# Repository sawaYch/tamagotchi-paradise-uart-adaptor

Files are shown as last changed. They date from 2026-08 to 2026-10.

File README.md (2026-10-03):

# Tamagotchi Paradise UART Adaptor



<figure>
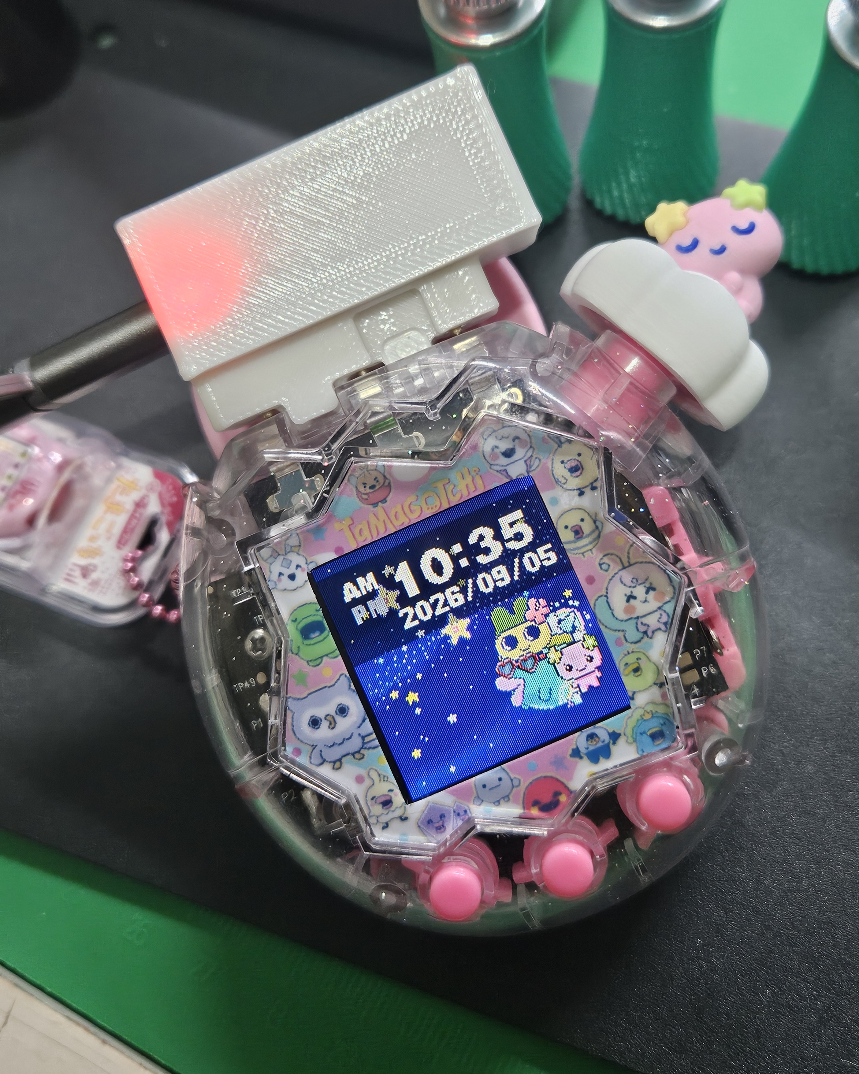
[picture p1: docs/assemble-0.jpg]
assemble-0

<figcaption>My adaptor plug to a Tamagotchi Paradise device 💗💖</figcaption>
</figure>

## Introduction

This is a UART adaptor for connecting your personal computer to Tamagotchi Paradise via `USB Type-C` cable.

## Install OpenSCAD

This project use OpenSCAD script to model the adaptor

```bash
# Windows
winget install -e --id OpenSCAD.OpenSCAD

# MacOS
brew install --cask openscad@snapshot
```

## Install just

```bash
# Windows
winget install -e --id Casey.Just

# MacOS
brew install just
```

## Generate .stl for 3D printing

Generate the printable wired adapter and lid:

```bash
just wire
```

Generate the printable wireless adapter and lid:

```bash
just wireless
```

Generate both with `just all`.

## Models

[Wired adapter](./models/wire/wire-adaptor.stl) · [Wired lid](./models/wire/wire-lid.stl) · [Wireless adapter](./models/wireless/wireless-adaptor.stl) · [Wireless lid](./models/wireless/wireless-lid.stl) · [Wireless tray cover](./models/wireless/wireless-tray-cover.stl)

## Components

### 1. FTL232RL USB to ttl module (USB Type-C)

<div style="display: flex; gap: 0px;">
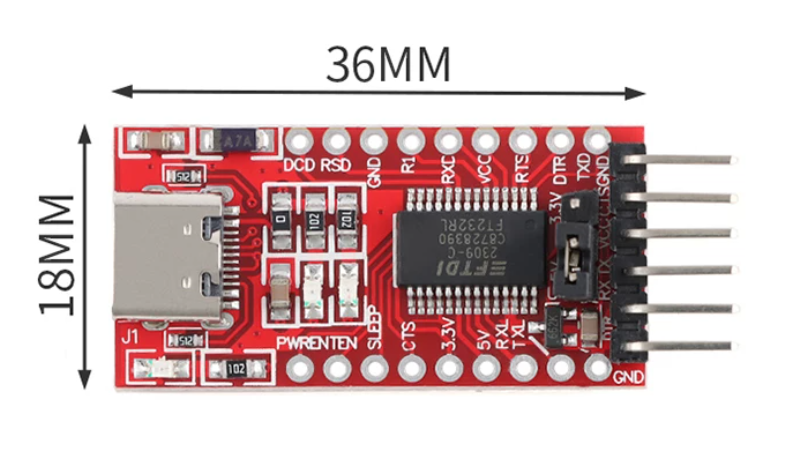
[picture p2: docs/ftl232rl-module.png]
ftl232rl-module
  
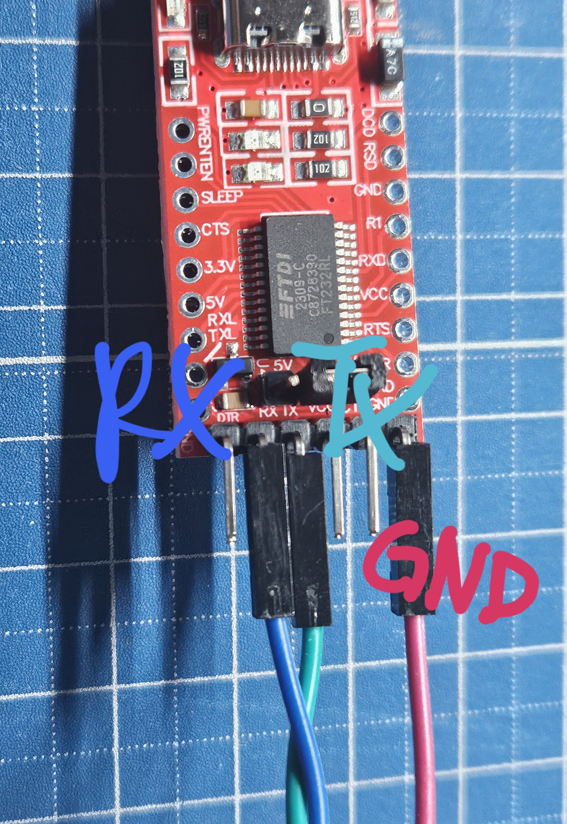
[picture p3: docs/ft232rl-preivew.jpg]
ftl232rl-preview
   
</div>

[Example Retail](https://item.taobao.com/item.htm?id=977654905255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)

🚨🚨🚨 **Tamagotchi Paradise only accept 3.3v for signal, please check your usb to ttl TX is output 3.3v otherwise it can damage your Tamagotchi Paradise device!!!** 🚨🚨🚨

Requirement:

- Tamagotchi Paradise require input signal with 3.3v, otherwise the command will failed / damage your tamagotchi device
- Baud rate need to support 460800

### 2. Pogo pins

It used for contact the top portion of the physical connector pins from Tamagotchi Paradise device. Notices that the size does matter.
Here I use A-SMT pin, (flat flange, no tail) with following spec:

```
Ø3 × 0.5 mm flange
Ø2 × 7.0 mm barrel
Ø1.5 × 2.5 mm plunger
10 mm overall.
```

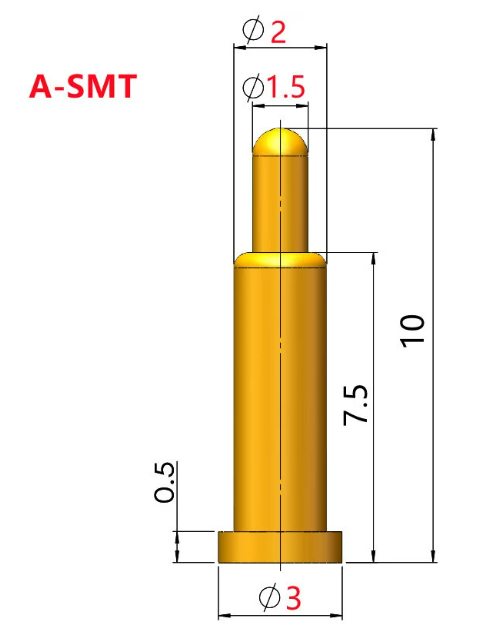
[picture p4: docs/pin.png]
pogopin
   
[Example Retail](https://item.taobao.com/item.htm?id=836549063705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)

### 3. Wire for soldering

Any wire (suggest to use 24 AWG) for soldering TX, RX, GND to the pogo pins.

## Connection Scheme

Soldering the pin reference to the following scheme, the left side of the adaptor plug your own USB type-c cable to your PC.

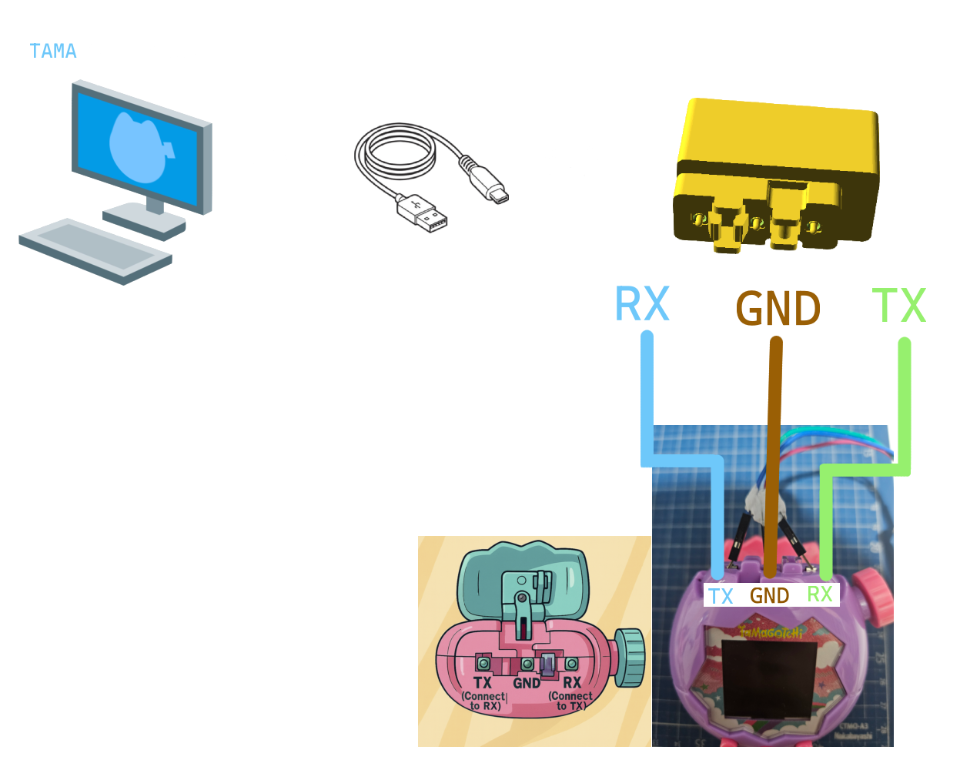
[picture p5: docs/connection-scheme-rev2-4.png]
connection-scheme
  

## Gallery
_Model 3D Print in FDM ABS_
<div style="display: flex; gap: 0px;">
asm-0  
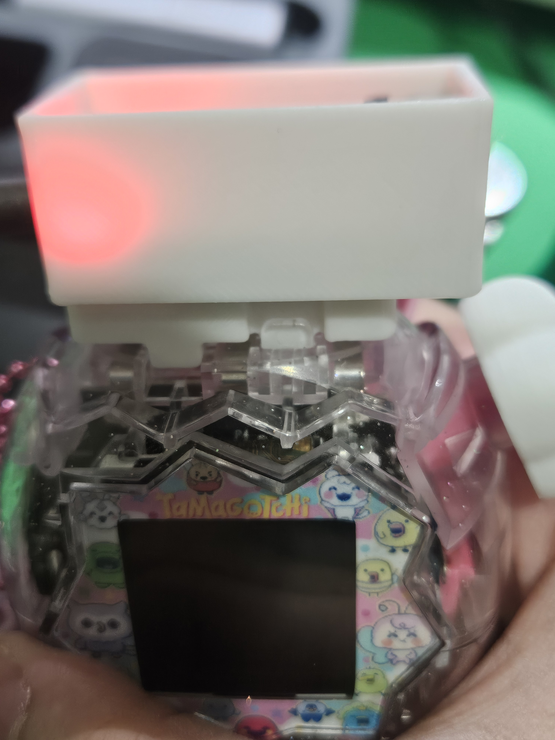
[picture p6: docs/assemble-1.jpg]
asm-1
  
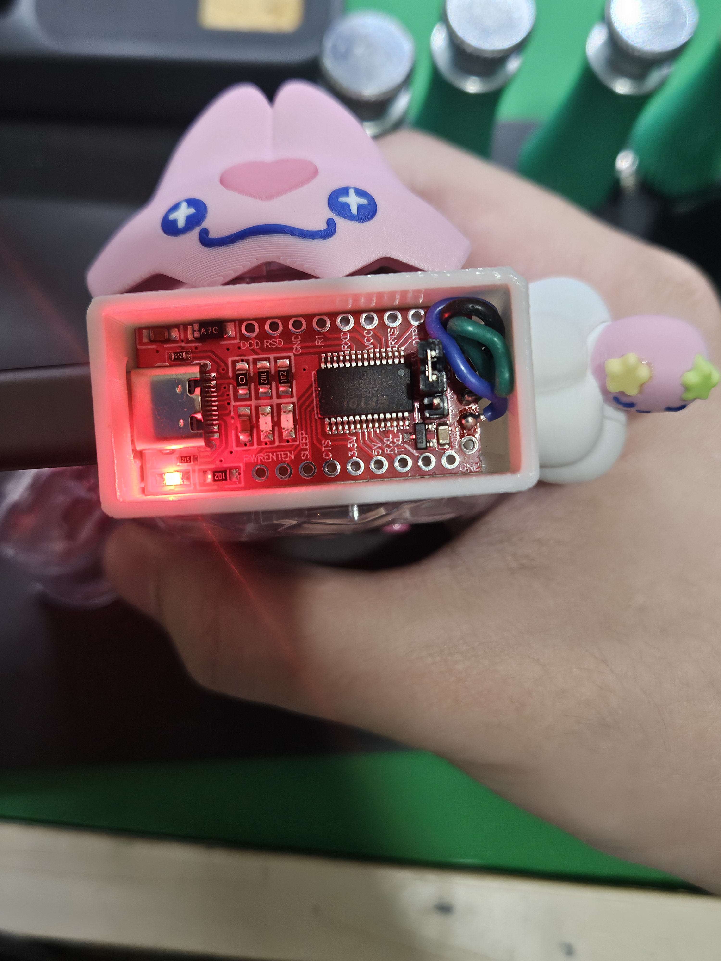
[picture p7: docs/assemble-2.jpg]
asm-2

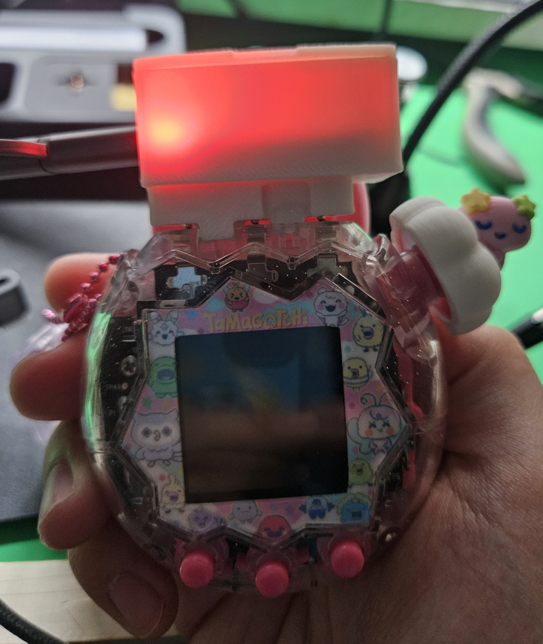
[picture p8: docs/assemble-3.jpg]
asm-3
     
</div>

## Special Thanks

This project reference and modified from hook model `./reference-stl/Basic_rev2.stl` [IgelFullmetal](https://www.thingiverse.com/thing:7310297) Creative Common License

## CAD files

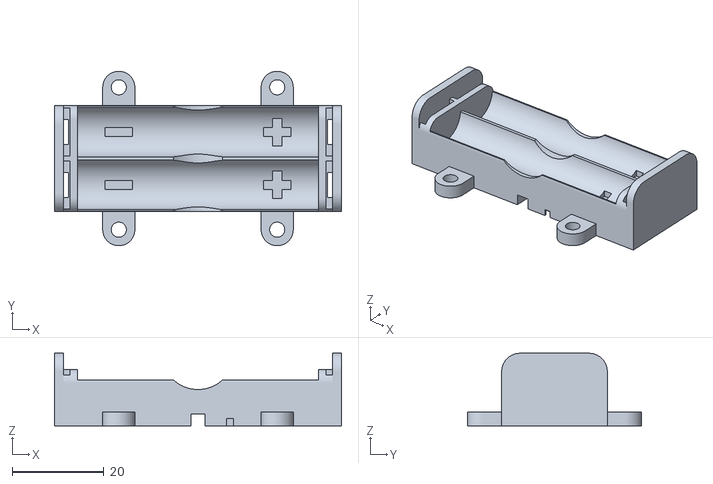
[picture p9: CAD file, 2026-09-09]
battery-box-aaa.stl
62.5 x 38.0 x 15.8

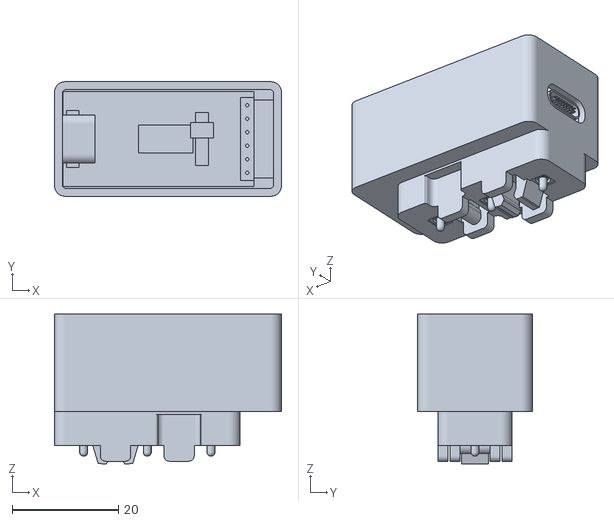
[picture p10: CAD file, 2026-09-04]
docs/preview-no-lid.stl
42.8 x 21.6 x 28.2

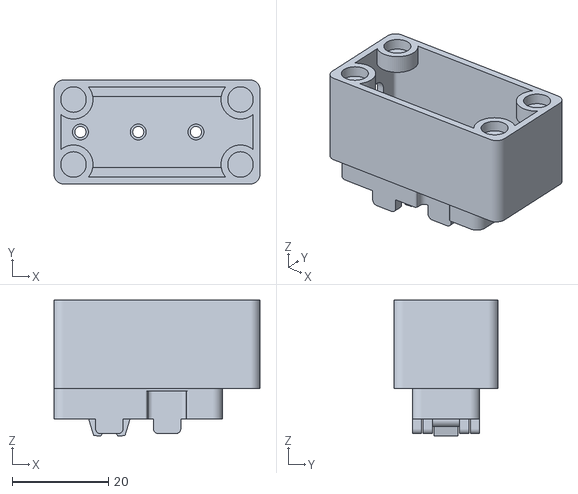
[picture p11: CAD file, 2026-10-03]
models/wire/wire-adaptor.stl
42.8 x 21.6 x 28.2

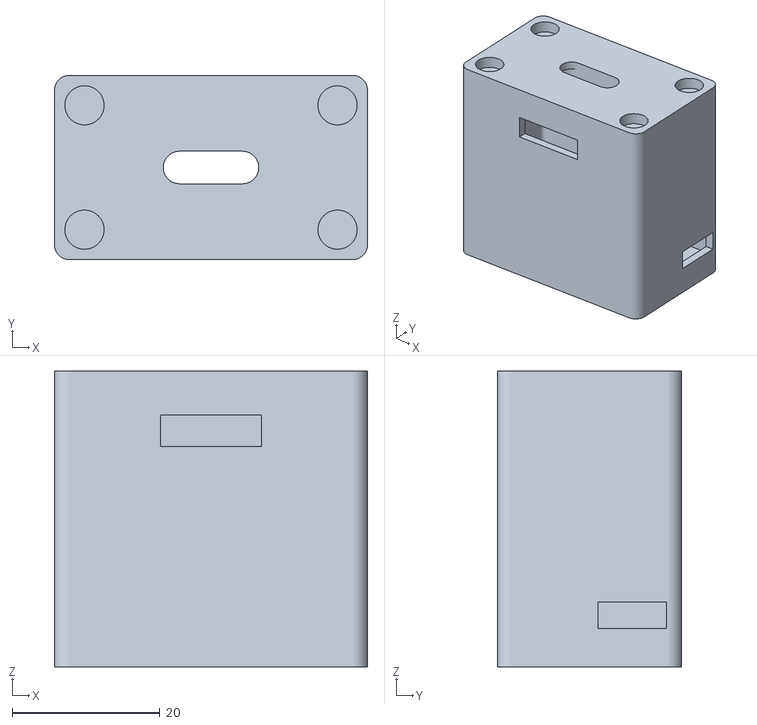
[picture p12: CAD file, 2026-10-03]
models/wireless/wireless-lid.stl
42.3 x 24.9 x 39.9

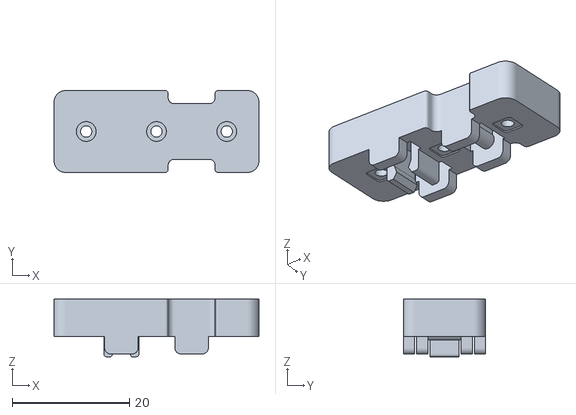
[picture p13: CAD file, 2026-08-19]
reference-stl/Basic_rev2.stl
35.0 x 14.0 x 9.85

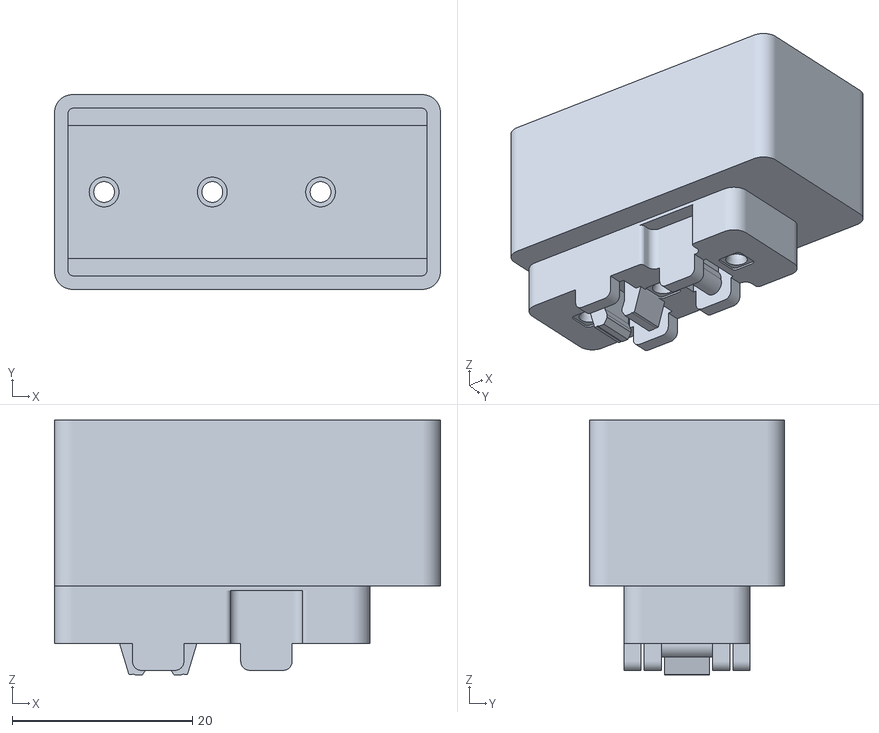
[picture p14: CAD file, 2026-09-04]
adapter.stl
42.8 x 21.6 x 28.2

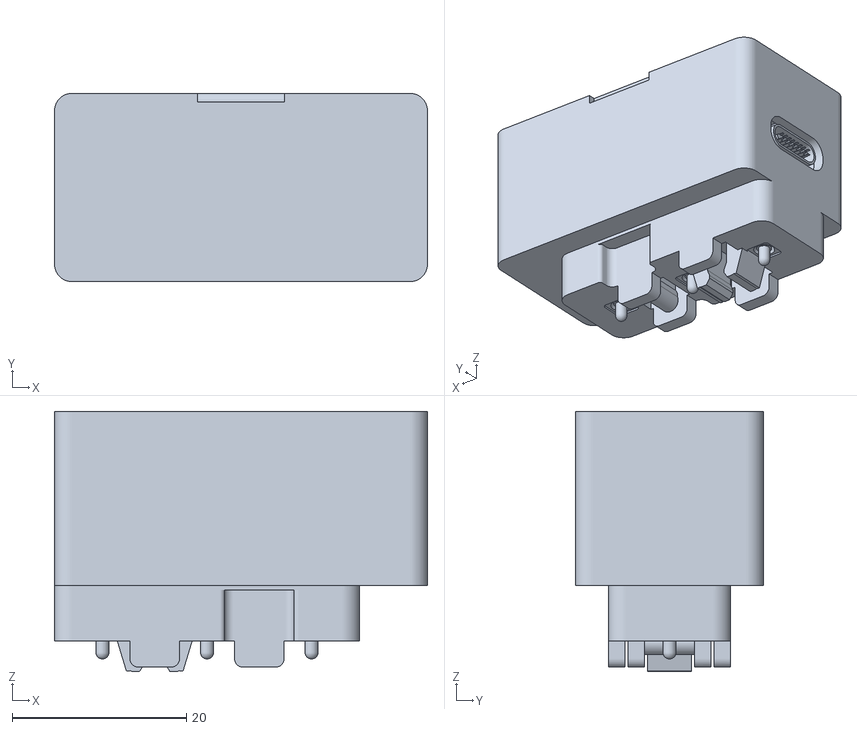
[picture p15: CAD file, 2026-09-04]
docs/preview-with-lid.stl
42.8 x 21.6 x 29.9

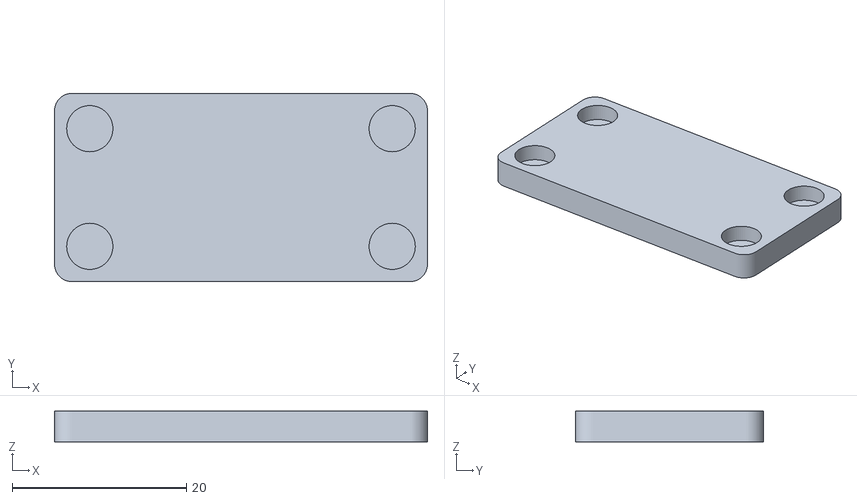
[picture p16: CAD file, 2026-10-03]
models/wire/wire-lid.stl
42.8 x 21.6 x 3.55

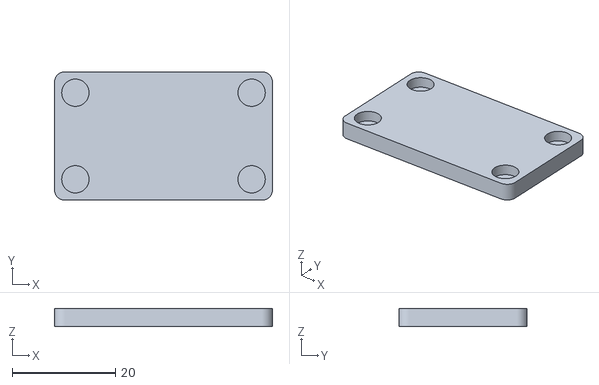
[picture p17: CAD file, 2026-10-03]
models/wireless/wireless-tray-cover.stl
42.3 x 24.9 x 3.55

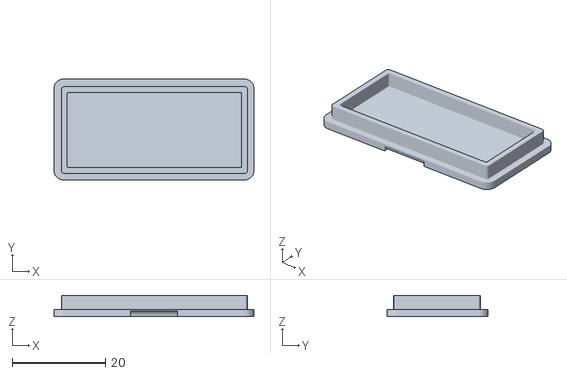
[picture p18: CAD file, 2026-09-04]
lid.stl
42.8 x 21.6 x 4.60

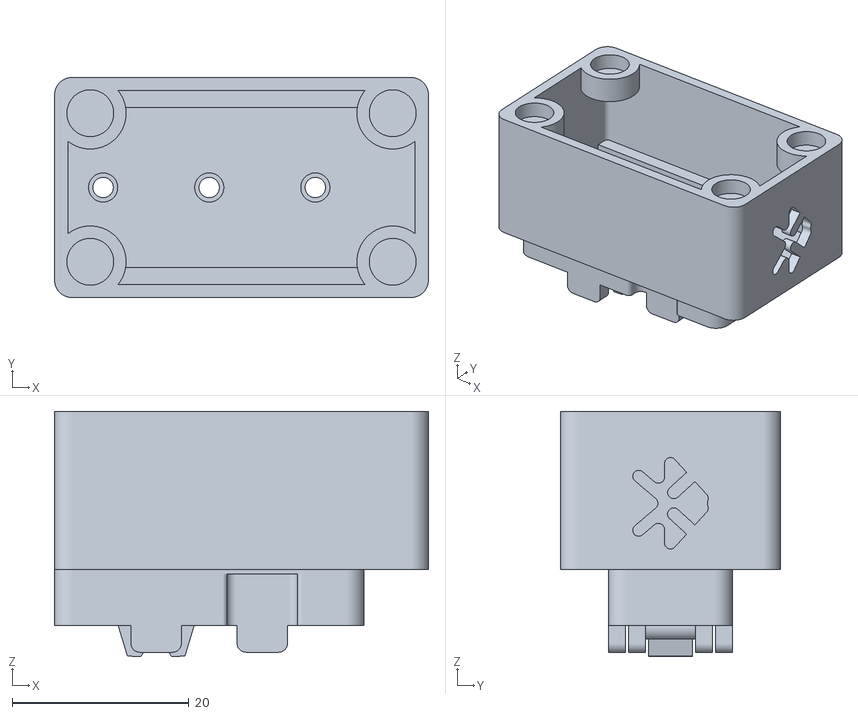
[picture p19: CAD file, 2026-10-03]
models/wireless/wireless-adaptor.stl
42.3 x 24.9 x 27.8

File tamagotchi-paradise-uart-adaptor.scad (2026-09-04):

// Tamagotchi Paradise UART adapter
// Hook (Basic_rev2.stl) + FT232RL pocket + internal friction-fit lid.

$fn = 64;
eps = 0.05;

tolerance = 0.2;
show_board_preview = true;
show_pin_preview = true;

// 0 = adapter, 1 = lid, 2 = assembled
// Use a number so `openscad -D part=0` works on Windows (no quoted strings).
part = 0;

// --- FT232RL USB-C module (36 x 18 mm) ---
pcb_l = 36.0;
pcb_w = 18.0;
pcb_thickness = 1.6;
jumper_h = 9.0;
pcb_h = pcb_thickness + jumper_h;
usb_w = 9.0;
usb_h = 3.2;
usb_overhang = 1.2;
usb_shell_l = 7.2;
usb_shell_w = 9.0;
usb_shell_h = 3.2;
header_overhang = 2.0;
pad_pitch_y = 2.54;
board_preview_angle = 0;
pcb_insert_x_offset = 0;
pcb_insert_y_offset = 0;

// --- Hook ---
stl_file = "reference-stl/Basic_rev2.stl";
hook_l = 35.0;
hook_w = 14.0;
hook_h = 6.35;
hook_r = 2.0;

// A-SMT pogo (pin.png), installed plunger-down, flange on pocket floor
pin_xs = [-12, 0, 12];
pin_flange_d = 3.0;
pin_flange_h = 0.5;
pin_barrel_d = 2.0;
pin_barrel_h = 7.0;
pin_tip_d = 1.5;
pin_tip_h = 2.5;
pin_hole_clear = 0.15;
pin_sleeve_od = 3.7;
pin_sleeve_z = 3.2;

// --- Pocket / lid ---
wall = 1.6;
wall_inner = wall - 0.1;
headroom = 0.6;
shell_extra = 2;

// Space under the PCB: solder fillet + 24 AWG + user-added isolator sheet
solder_h = 1.0;
wire_od = 1.4;
isolator_h = 1.0;
solder_well_h = solder_h + wire_od;
board_lift = solder_well_h + isolator_h;
ledge_w = 1.8;
ledge_h = 1.2;

usb_cut_tol = 0.6;
usb_cut_round_r = 2.5;

lid_t = 1.6;
lid_inner_clear = 0.03;
lid_inner_h = 3.0;
lid_inner_t = 1.2;
lid_snap_d = 0.5;
lid_snap_h = 1.6;
lid_snap_w = 14.0;
lid_snap_lift = 0.7;
lid_pry_w = 10.0;
lid_pry_d = 1.2;

// --- Hook reinforcement (imported Basic_rev2.stl) ---
prong_root_y = -2.5;
prong_root_w = 5.0;
prong_root_depth = 3.45;
prong_root_extra = 1.25;
prong_root_overlap = 0.25;

// Detent faces that clip the Tamagotchi's grab bar (measured from STL)
prong_grab_shave = 0.1;
prong_grab_face_l = -7.112;
prong_grab_face_r = -4.888;
prong_grab_z = -2.49;

grab_cyl_x = 6.0;
grab_cyl_z = -0.20;
grab_cyl_d = 2.64; // original = ~2.4mm
grab_cyl_len = 5.7;

// --- Derived ---
pcb_cav_l = pcb_l + 2 * tolerance + usb_overhang + header_overhang;
pcb_cav_w = pcb_w + 2 * tolerance;
pcb_cav_h = pcb_h + tolerance + headroom;
shell_h = wall + board_lift + pcb_cav_h + shell_extra;

usb_cut_w = usb_w + 2 * tolerance + 0.6;
usb_cut_h = usb_h + 2 * tolerance;

hook_x0 = -hook_l / 2;
hook_y0 = -hook_w / 2;
shell_x0 = hook_x0;
shell_l = pcb_cav_l + 2 * wall;
shell_x1 = shell_x0 + shell_l;
shell_y0 = -pcb_cav_w / 2 - wall;
shell_y1 = pcb_cav_w / 2 + wall;
shell_w = shell_y1 - shell_y0;
shell_ox = shell_x0 + pcb_insert_x_offset;
shell_oy = shell_y0 + pcb_insert_y_offset;

pin_barrel_hole = pin_barrel_d + 2 * pin_hole_clear;
pin_flange_hole = pin_flange_d + 2 * pin_hole_clear;
pin_floor_z = hook_h + wall;
pin_seat_z = pin_floor_z - pin_flange_h;
pcb_z = pin_floor_z + board_lift;
ledge_z = pin_floor_z + solder_well_h - ledge_h;

if (part == 1) {
    lid();
} else {
    adapter();
    if (part == 2)
        color([0.25, 0.55, 0.85, 0.72])
            lid();
}

module adapter() {
    union() {
        difference() {
            union() {
                hook();
                pcb_shell();
                pin_sleeves();
                prong_root_reinforcement();
                grab_cylinder();
            }
            pcb_cavity();
            usb_cutout();
            pin_through_holes();
            prong_grab_relief();
            //lid_inner_snap_recesses();
        }
        isolator_ledges();
    }
    if (show_board_preview)
        board_preview();
    if (show_pin_preview)
        pin_preview();
}

module hook() {
    import(stl_file, convexity = 16);
}

module pcb_shell() {
    translate([shell_ox, shell_oy, hook_h])
        rounded_cube([shell_l, shell_w, shell_h], hook_r);

    translate([hook_x0, hook_y0, hook_h - 0.5])
        rounded_cube([hook_l, hook_w, 0.5 + eps], hook_r);
}

module pcb_cavity() {
    translate([shell_ox + wall_inner, shell_oy + wall_inner, hook_h + wall])
        rounded_cube([
            shell_l - 2 * wall_inner,
            shell_w - 2 * wall_inner,
            shell_h - wall + 1
        ], 0.6);
}

module usb_cutout() {
    cut_w = usb_cut_w + 2 * usb_cut_tol;
    cut_h = usb_cut_h + 2 * usb_cut_tol;
    depth = wall + 6;
    r = min(usb_cut_round_r, cut_w / 2 - 0.2, cut_h / 2 - 0.2);
    x0 = shell_ox - 0.2;
    y0 = shell_oy + (shell_w - cut_w) / 2;
    z0 = pcb_z + pcb_thickness + usb_h / 2;

    translate([x0, y0 + cut_w / 2, z0])
        rotate([0, 90, 0])
            linear_extrude(height = depth)
                offset(r = r)
                    square([cut_h - 2 * r, cut_w - 2 * r], center = true);
}

module pin_sleeves() {
    h = pin_floor_z - pin_sleeve_z + 0.2;
    for (x = pin_xs)
        translate([x, 0, pin_sleeve_z])
            cylinder(h = h, d = pin_sleeve_od);
}

module pin_through_holes() {
    for (x = pin_xs) {
        translate([x, 0, -1])
            cylinder(h = pin_floor_z + 2, d = pin_barrel_hole);
        translate([x, 0, pin_seat_z])
            cylinder(h = pin_flange_h + 1, d = pin_flange_hole);
        translate([x, 0, -0.2])
            cylinder(h = 1.2, d1 = pin_barrel_hole + 0.8, d2 = pin_barrel_hole);
    }
}

module pin_preview() {
    for (x = pin_xs)
        translate([x, 0, pin_seat_z])
            pogo_pin();
}

module pogo_pin() {
    color([0.90, 0.75, 0.20, 0.95]) {
        cylinder(h = pin_flange_h, d = pin_flange_d);
        translate([0, 0, -pin_barrel_h])
            cylinder(h = pin_barrel_h, d = pin_barrel_d);
        translate([0, 0, -pin_barrel_h - pin_tip_h + pin_tip_d / 2]) {
            cylinder(h = pin_tip_h - pin_tip_d / 2, d = pin_tip_d);
            sphere(d = pin_tip_d);
        }
    }
}

module board_preview() {
    board_x0 = hook_x0 + wall;
    board_y0 = -pcb_w / 2;
    ic_l = 10.3;
    ic_w = 5.3;
    ic_h = 1.65;
    jumper_x = board_x0 + 26.2;
    jumper_post_h = 2.5;
    header_x = board_x0 + pcb_l - 2.5;
    header_body_w = 6 * pad_pitch_y + 0.5;

    translate([pcb_insert_x_offset, pcb_insert_y_offset, pcb_z])
        rotate([0, 0, board_preview_angle])
            union() {
                color([0.78, 0.12, 0.14, 0.82])
                    translate([board_x0, board_y0, 0])
                        cube([pcb_l, pcb_w, pcb_thickness]);

                translate([board_x0 - usb_overhang, 0, pcb_thickness])
                    usb_c_receptacle();

                color([0.10, 0.10, 0.10, 0.96])
                    translate([
                        board_x0 + 14.2,
                        -ic_w / 2,
                        pcb_thickness
                    ])
                        cube([ic_l, ic_w, ic_h]);

                color([0.12, 0.12, 0.12, 0.96])
                    translate([
                        jumper_x - 1.25,
                        -pad_pitch_y * 1.5 - 1.2,
                        pcb_thickness
                    ])
                        cube([2.5, pad_pitch_y * 3 + 2.4, jumper_post_h]);

                color([0.08, 0.08, 0.08, 0.96])
                    translate([jumper_x - 2.2, 0.2, pcb_thickness + jumper_post_h])
                        cube([4.4, pad_pitch_y + 0.4, jumper_h - jumper_post_h]);

                color([0.12, 0.12, 0.12, 0.96])
                    translate([
                        header_x,
                        -header_body_w / 2,
                        pcb_thickness
                    ])
                        cube([2.5, header_body_w, 2.5]);

                for (p = [1 : 6]) {
                    py = (3.5 - p) * pad_pitch_y;
                    pin_col =
                        p == 2 ? [0.35, 0.72, 0.95, 0.95] :
                        p == 3 ? [0.25, 0.85, 0.40, 0.95] :
                        p == 6 ? [0.55, 0.32, 0.16, 0.95] :
                                 [0.82, 0.68, 0.18, 0.92];

                    translate([header_x + 1.25, py, pcb_thickness + 2.5])
                        color(pin_col)
                            cylinder(h = 4.2, d = 0.64);
                }
            }
}

module usb_c_receptacle() {
    w = usb_shell_w;
    h = usb_shell_h;
    l = usb_shell_l;
    metal_t = 0.32;
    cavity_l = 5.5;
    inner_w = w - 2 * metal_t;
    inner_h = h - 2 * metal_t;
    tongue_w = 6.55;
    tongue_h = 0.72;
    tongue_l = 4.3;
    tab_l = 2.4;
    tab_w = 0.85;
    tab_h = 0.28;

    color([0.76, 0.78, 0.81, 0.96])
        difference() {
            usb_c_capsule(l, w, h);
            translate([-eps, 0, metal_t])
                usb_c_capsule(cavity_l + eps, inner_w, inner_h);
        }

    color([0.10, 0.10, 0.11, 0.96]) {
        translate([cavity_l - 0.35, 0, metal_t + 0.08])
            usb_c_capsule(l - cavity_l + 0.35, inner_w - 0.2, inner_h - 0.16);
        translate([0.28, 0, (h - tongue_h) / 2])
            usb_c_capsule(tongue_l, tongue_w, tongue_h);
    }
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

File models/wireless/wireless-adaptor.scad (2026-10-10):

// Tamagotchi Paradise wireless UART adapter
// Hook (Basic_rev2.stl) + JDY-23 BLE pocket + magnetic power tray + cover.

$fn = 64;
eps = 0.05;

tolerance = 0.2;
show_board_preview = false;
show_pin_preview = false;
show_magnet_preview = false;

// 0 = adapter, 1 = power tray, 2 = assembled, 3 = tray cover
// Use a number so `openscad -D part=0` works on Windows (no quoted strings).
part = 2;

// --- JDY-23 BLE 5.0 module with base plate (32.7 x 18.3 mm) ---
pcb_l = 32.7;
pcb_w = 18.3;
pcb_thickness = 1.6;
// SMT module stack on the carrier (~19.6 x 14.94 x 1.8) plus pin header clearance
module_l = 19.6;
module_w = 14.94;
module_h = 1.8;
header_h = 8.5;
pcb_h = pcb_thickness + header_h;
pad_pitch_y = 2.54;
board_preview_angle = 0;
pcb_insert_x_offset = 0;
pcb_insert_y_offset = 0;

// --- Hook ---
stl_file = "../../reference-stl/Basic_rev2.stl";
hook_l = 35.0;
hook_w = 14.0;
hook_h = 6.35;
hook_r = 2.0;

// A-SMT pogo (pin.png), installed plunger-down, flange on pocket floor
pin_xs = [-12, 0, 12];
pin_flange_d = 3.0;
pin_flange_h = 0.5;
pin_barrel_d = 2.0;
pin_barrel_h = 7.0;
pin_tip_d = 1.5;
pin_tip_h = 2.5;
pin_hole_clear = 0.15;
pin_sleeve_od = 3.7;
pin_sleeve_z = 3.2;

// --- Pocket / lid ---
wall = 1.6;
wall_inner = wall - 0.1;
// JLC3DP: walls > 1.2 mm, and nothing thinner than 0.8 mm.
min_wall = 1.4;
headroom = 0.6;
shell_extra = 2;

// Extra pocket around the JDY-23 pin header for soldering TX/RX/GND/VCC wires
pin_solder_clear = 6.0; // along X, ahead of the header (toward pogo pins)
side_wire_clear = 1.5; // each Y side beyond fit tolerance

// Bluetooth-symbol windows on both end walls
ble_symbol_h = 9.0;
ble_symbol_stroke = 1.35;

// Space under the PCB: solder fillet + 24 AWG + user-added isolator sheet
solder_h = 1.0;
wire_od = 1.4;
isolator_h = 1.0;
solder_well_h = solder_h + wire_od;
board_lift = solder_well_h + isolator_h;
ledge_w = 1.8;
ledge_h = min_wall;

// 5 x 2 mm N52 discs, one pair at each corner. 2 mm is thick enough to
// hold this lid (~0.6 kg pull per magnet) without a deep pocket.
mag_d = 5.0;
mag_h = 2.0;
mag_fit = 0.3;
mag_pocket_d = mag_d + mag_fit;
mag_pocket_h = mag_h + 0.15;
mag_floor = min_wall;
mag_wall_skin = min_wall;
mag_inset = mag_pocket_d / 2 + mag_wall_skin;
mag_boss_d = mag_pocket_d + 2 * min_wall;
mag_boss_h = mag_pocket_h + mag_floor;

// Female pogo housing in tray floor (ears seat on a ledge, insert from the lid cavity)
fp_body_l = 12.5;
fp_ear_l = 14.5;
fp_w = 4.0;
fp_h = 4.0;
fp_ear_t = 1.0;
fp_fit = 0.2;

// --- Power tray components ---
// 102535 LiPo 1000 mAh
batt_l = 35.0;
batt_w = 25.0;
batt_t = 10.0;
// MiniUPS-3.3V
ups_l = 35.0;
ups_w = 21.0;
ups_t = 5.6;
// SS-12D10-G5 slide switch
sw_l = 12.7;
sw_w = 6.7;
sw_h = 11.3;
sw_body_h = 6.5;
sw_act_travel = 2.2;
sw_act_l = 11.5;
sw_act_h = 4.2;
// Vertical USB-C opening on the +X end wall (plug long axis along Z).
// Insets are from the outer case to the opening edges.
usbc_w = 3.6;
usbc_h = 9.5;
usbc_side_inset = 3.5;
usbc_top_inset = 16.0;
// Status-LED grille just above that opening
led_hole_d = 1.5;
led_hole_pitch = 2.5;
led_hole_cols = 5;
led_hole_rows = 3;
led_hole_gap = 1.6;

comp_fit = 0.4;
// Battery stands on its thin face so tray width can match the adapter:
// footprint 35(L)×10(T), height 25(W) — makes the lid taller.
batt_bay_l = batt_l + comp_fit;
batt_bay_w = batt_t + comp_fit;
batt_bay_h = batt_w + comp_fit;
ups_pl = ups_l + comp_fit;
ups_pw = ups_w + comp_fit;
ups_pt = ups_t + 0.2;
sw_pl = sw_l + 0.4;
sw_pw = sw_w + 0.3;

tray_roof = 0.8;
tray_floor = fp_h + tray_roof;
// Lip must clear corner magnet bosses above the MiniUPS
tray_lip = mag_boss_h + 0.4;
tray_gap_sw = 0.6;
tray_inner_l = max(batt_bay_l, ups_pl) + 1.0;
tray_cavity_h = batt_bay_h + ups_pt + tray_lip;
tray_h = tray_floor + tray_cavity_h;
cover_h = mag_pocket_h + mag_floor;
cover_pry_w = 10.0;
cover_pry_d = 1.2;
pogo_wire_slot_w = 2.2;
pogo_wire_slot_l = 6.0;

// Kuchipatchi outline on the plain long wall, opposite the slide switch.
kuchipatchi_margin_z = 2.6;
kuchipatchi_depth = 0.4;
// Height of kuchipatchi.svg as imported, in mm.
kuchipatchi_art_h = 34.75;

// Paradise wordmark on the switch side, centered on that wall.
paradise_margin_x = 2.8;
paradise_depth = 0.4;
// Width of paradise-logo.svg as imported, in mm.
paradise_art_w = 36.70;

// --- Hook reinforcement (imported Basic_rev2.stl) ---
prong_root_y = -2.5;
prong_root_w = 5.0;
prong_root_depth = 3.45;
prong_root_extra = 1.25;
prong_root_overlap = 0.25;

// Detent faces that clip the Tamagotchi's grab bar (measured from STL)
prong_grab_shave = 0.1;
prong_grab_face_l = -7.112;
prong_grab_face_r = -4.888;
prong_grab_z = -2.49;

grab_cyl_x = 6.0;
grab_cyl_z = -0.20;
grab_cyl_d = 2.64; // original = ~2.4mm
grab_cyl_len = 5.7;

// --- Derived ---
pcb_cav_l = pcb_l + 2 * tolerance + pin_solder_clear;
pcb_cav_w = pcb_w + 2 * tolerance + 2 * side_wire_clear;
pcb_cav_h = pcb_h + tolerance + headroom;
shell_h = wall + board_lift + pcb_cav_h + shell_extra;

hook_x0 = -hook_l / 2;
hook_y0 = -hook_w / 2;
shell_x0 = hook_x0;
shell_l = pcb_cav_l + 2 * wall;
shell_x1 = shell_x0 + shell_l;
shell_y0 = -pcb_cav_w / 2 - wall;
shell_y1 = pcb_cav_w / 2 + wall;
shell_w = shell_y1 - shell_y0;
shell_ox = shell_x0 + pcb_insert_x_offset;
shell_oy = shell_y0 + pcb_insert_y_offset;

tray_l = max(tray_inner_l + 2 * wall, shell_l);
// Match adapter width (no Y overhang); height grows instead
tray_w = shell_w;
mate_ox = 0;
mate_oy = 0;
// Stack flush to the +X free wall so MiniUPS USB-C reaches the cutout
batt_x = tray_l - wall - batt_bay_l;
batt_y = wall;
ups_x = tray_l - wall - ups_pl;
ups_y = (tray_w - ups_pw) / 2;
sw_x = wall + (tray_l - 2 * wall - sw_pl) / 2;
sw_y = wall + batt_bay_w + tray_gap_sw;

// Board sits past the solder pocket so the pin header is not against the wall
board_x0 = hook_x0 + wall + pin_solder_clear;
board_y0 = -pcb_w / 2;

pin_barrel_hole = pin_barrel_d + 2 * pin_hole_clear;
pin_flange_hole = pin_flange_d + 2 * pin_hole_clear;
pin_floor_z = hook_h + wall;
pin_seat_z = pin_floor_z - pin_flange_h;
pcb_z = pin_floor_z + board_lift;
ledge_z = pin_floor_z + solder_well_h - ledge_h;

if (part == 1) {
  lid();
} else if (part == 3) {
  tray_cover();
} else {
  adapter();
  if (part == 2) {
    color([0.25, 0.55, 0.85, 0.72])
      lid();
    color([0.35, 0.65, 0.45, 0.72])
      tray_cover();
  }
}

module adapter() {
  difference() {
    union() {
      difference() {
        union() {
          hook();
          pcb_shell();
          pin_sleeves();
          prong_root_reinforcement();
          hook_rib_fill();
          grab_cylinder();
        }
        pcb_cavity();
        ble_cutout();
        pin_through_holes();
        prong_grab_relief();
      }
      isolator_ledges();
      magnet_bosses_case();
    }
    magnet_pockets_case();
  }
  if (show_board_preview)
    board_preview();
  if (show_pin_preview)
    pin_preview();
  if (show_magnet_preview)
    magnet_preview_case();
}

module hook() {
  import(stl_file, convexity=16);
}

module pcb_shell() {
  translate([shell_ox, shell_oy, hook_h])
    rounded_cube([shell_l, shell_w, shell_h], hook_r);

  translate([hook_x0, hook_y0, hook_h - 0.5])
    rounded_cube([hook_l, hook_w, 0.5 + eps], hook_r);
}

module pcb_cavity() {
  translate([shell_ox + wall_inner, shell_oy + wall_inner, hook_h + wall])
    rounded_cube(
      [
        shell_l - 2 * wall_inner,
        shell_w - 2 * wall_inner,
        shell_h - wall + 1,
      ], 0.6
    );
}

module ble_cutout() {
  z0 = pcb_z + pcb_thickness + module_h / 2;
  // Free (+X) end, through the antenna wall
  ble_symbol_window(shell_ox + shell_l + 0.2, z0, -90, 90, wall + 6);
  // Hook (-X) end. Shorter depth so the cut stops clear of the pogo sleeves.
  ble_symbol_window(shell_ox - 0.2, z0, 90, 270, wall + 2);
}

module ble_symbol_window(x0, z0, tilt, spin, depth) {
  translate([x0, 0, z0])
    rotate([0, tilt, 0])
      linear_extrude(height=depth)
        rotate([0, 0, spin])
          bluetooth_symbol_2d(ble_symbol_h, ble_symbol_stroke);
}

// Classic Bluetooth rune: vertical stem, right-pointing B bowls, left X arms.
// Close gaps narrower than min_wall so the window leaves no thin ribs.
module bluetooth_symbol_2d(height, stroke) {
  difference() {
    offset(r=-min_wall / 2)
      offset(r=min_wall / 2)
        bluetooth_symbol_strokes(height, stroke);
    bluetooth_symbol_bridges(height, stroke);
  }
}

module bluetooth_symbol_strokes(height, stroke) {
  h = height;
  t = stroke;
  tip_x = h * 0.40;
  mid_y = h * 0.06;
  union() {
    bluetooth_bar([0, h / 2], [0, -h / 2], t);
    bluetooth_bar([0, h / 2], [tip_x, mid_y], t);
    bluetooth_bar([tip_x, mid_y], [0, -mid_y], t);
    bluetooth_bar([0, mid_y], [tip_x, -mid_y], t);
    bluetooth_bar([tip_x, -mid_y], [0, -h / 2], t);
    bluetooth_bar([-tip_x, h * 0.34], [0, 0], t);
    bluetooth_bar([-tip_x, -h * 0.34], [0, 0], t);
  }
}
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

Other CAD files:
models/wire/wire-adaptor.scad

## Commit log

2026-08-19 feat: init tamagotchi paradise uart adaptor v0.1
    [Basic_rev2.stl, tamagotchi-paradise-uart-adaptor.scad]
2026-08-19 fix: usb type-c cutout in better postion
    [tamagotchi-paradise-uart-adaptor.scad]
2026-08-19 fix: remove n/a pcb stop
    [tamagotchi-paradise-uart-adaptor.scad]
2026-08-19 fix: adapter case opened top
    [tamagotchi-paradise-uart-adaptor.scad]
2026-08-19 fix: adjust the usb cutout position
    [tamagotchi-paradise-uart-adaptor.scad]
2026-08-19 feat: done v0.1 design
    [tamagotchi-paradise-uart-adaptor.scad]
2026-08-19 fix: better usb c preview
    [tamagotchi-paradise-uart-adaptor.scad]
2026-08-19 fix: add stl for 3D printing
    [tamagotchi-paradise-uart-adaptor-lid.stl, tamagotchi-paradise-uart-adaptor.stl]
2026-08-19 fix: cleanup code
    [tamagotchi-paradise-uart-adaptor.scad]
2026-08-19 feat: update README.md
    [Basic_rev2.stl, lid.stl, tamagotchi-paradise-uart-adaptor-lid.stl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]
2026-08-19 feat: update preview stl
    [preview-no-lid.stl, tamagotchi-paradise-uart-adaptor.scad]
2026-08-20 feat: update preview stl (with lid closed)
2026-08-20 fix: update lid model & preview for usb type-c cutout
    [lid.stl, tamagotchi-paradise-uart-adaptor.scad]
2026-08-26 feat: update model rev2
    [adapter.stl, lid.stl, preview-no-lid.stl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]
2026-08-27 feat: update model rev2.1
    [adapter.stl, lid.stl, preview-no-lid.stl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]
2026-08-27 feat: update model rev2.2
    [tamagotchi-paradise-uart-adaptor.scad]
2026-08-27 feat: update model rev2.3
    [adapter.stl, lid.stl, preview-no-lid.stl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]
2026-09-04 docs: update README.md and show actual assemble
2026-09-04 feat: update model rev2.4
    [adapter.stl, lid.stl, preview-no-lid.stl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]
2026-09-09 wip(wireless): add 3A battery box design
    [battery-box-aaa.stl, battery-box.scad]
2026-09-10 feat: update project folder structure
    [wire-adaptor.scad, wire-adaptor.stl, wire-lid.stl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]
2026-09-11 feat: add ble cutout
    [wireless-adaptor.scad]
2026-09-25 feat(wireless): update case & lid for wireless adaptor
    [wireless-3a-battery.scad, wireless-3a-battery.stl, wireless-adaptor.scad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]
2026-10-02 wip: battery case
    [wireless-adaptor.scad, wireless-adaptor.stl, wireless-lid.stl]
2026-10-03 feat: release wireless ver.1
    [wireless-adaptor.scad, wireless-adaptor.stl, wireless-lid.stl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]
2026-10-03 fix: thicken printed walls for JLC3DP
    Raise walls and thin features to at least 1.4 mm so every printable part
    clears JLC3DP's limits (walls > 1.2 mm, nothing under 0.8 mm).
    [wire-adaptor.scad, wire-adaptor.stl, wire-lid.stl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]
2026-10-03 feat(wire): update wire adaptor to use magnet lid
    [wire-adaptor.scad, wire-adaptor.stl, wire-lid.stl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]
2026-10-10 fix(wireless): finetune charging usb type-c postion
    [wireless-adaptor.scad]
2026-10-10 fix(wire): finetune prong_grab params
    [wire-adaptor.scad]
2026-10-10 feat: add logo
    [wire-adaptor.scad, wireless-adaptor.scad]
2026-10-11 feat: update output stl model
2026-10-11 fix(wireless): align bluetooth symobl facing direction
2026-10-19 fix(wireless): add mode toggle switch cutout
2026-10-26 fix(wireless): add module insertion cutout

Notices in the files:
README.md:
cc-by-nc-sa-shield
